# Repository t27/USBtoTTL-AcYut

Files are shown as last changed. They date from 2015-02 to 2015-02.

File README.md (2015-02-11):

#USB to TTL Converter

This is a boar which converts USB to Half Duplex TTL(Serial). It is used for communicating with the Robotis Dynamixel line of motors. 

USB is converted to Serial using FTDI FT232RL and then to half duplex using a combinatino of Tri-State buffers.

Built for Team AcYut at CRIS, BITS Pilani.

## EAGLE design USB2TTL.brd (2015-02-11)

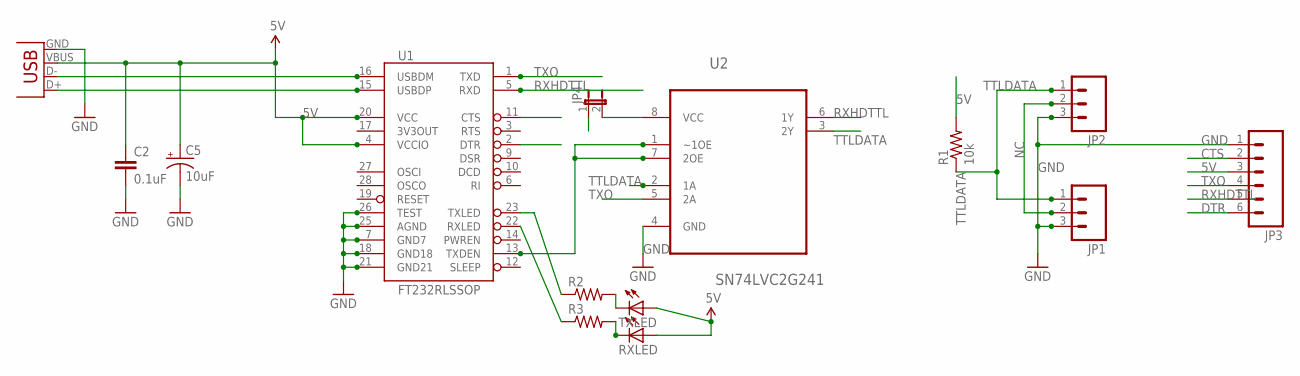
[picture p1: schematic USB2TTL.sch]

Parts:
C2: 0.1uF; 0402-CAP
C5: 10uF; EIA3216
JP1, JP2: M03LOCK_LONGPADS; 1X03_LOCK_LONGPADS
JP3: M06LOCK; 1X06_LOCK
JP4: JUMPER-2-OLDSMD-NO; SJ_2S-NO
R1: 10k; 0603-RES
R2, R3: RESISTOR0603-RES; 0603-RES
RXLED: LED0603; LED-0603
TXLED: LED0603; LED-0603
U1: FT232RLSSOP; SSOP28DB
U2: SN74LVC2G241; SOP65P400X130-8N
X2: USB-SMD-NS; USB-MINIB-NOSTOP

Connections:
5V: C2.1, C5.A (+), JP3.3, JP4.1, R1.2, RXLED.A, TXLED.A, U1.4 (VCCIO), U1.20 (VCC), X2.VBUS
CTS: JP3.2, U1.11 (CTS)
DTR: JP3.6, U1.2 (DTR)
GND: C2.2, C5.C (-), JP1.3, JP2.3, JP3.1, U1.7 (GND7), U1.18 (GND18), U1.21 (GND21), U1.25 (AGND), U1.26 (TEST), U2.4 (GND), X2.GND
unnamed: JP4.2, U2.8 (VCC)
unnamed: R2.1, U1.23 (TXLED)
unnamed: R3.1, U1.22 (RXLED)
unnamed: R2.2, TXLED.C
unnamed: R3.2, RXLED.C
NC: JP1.2, JP2.2
RXHDTTL: JP3.5, U1.5 (RXD), U2.6 (1Y)
TTLDATA: JP1.1, JP2.1, R1.1, U2.2 (1A), U2.3 (2Y)
TXDEN: U1.13 (TXDEN), U2.1 (~1OE), U2.7 (2OE)
TXO: JP3.4, U1.1 (TXD), U2.5 (2A)
USB_D+: U1.15 (USBDP), X2.D+
USB_D-: U1.16 (USBDM), X2.D-

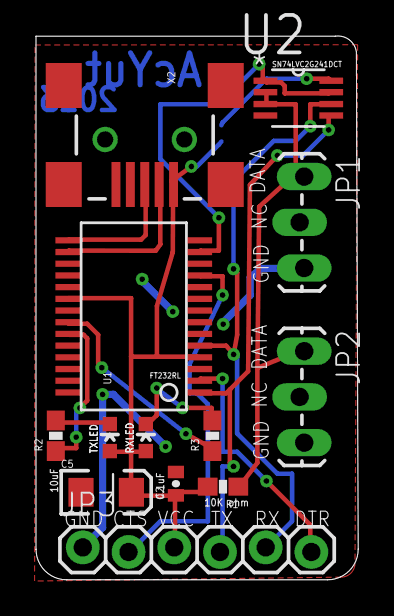
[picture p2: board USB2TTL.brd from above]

Board: 2 copper layers, 17.9 x 30.2 mm, 14 parts (1 on the bottom side), 16 nets.

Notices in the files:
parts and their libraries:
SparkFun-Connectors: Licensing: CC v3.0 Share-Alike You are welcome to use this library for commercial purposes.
